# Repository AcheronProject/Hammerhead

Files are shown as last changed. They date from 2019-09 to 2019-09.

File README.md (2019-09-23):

# Acheron 40-SM-S-STM32-MXSM-TH-WI (Codename "Hammerhead")

Acheron Logo

See [this page](https://gondolindrim.github.io/AcheronDocs/hammerhead/intro.html) for the Hammerhead documentation.

## Introduction

The Hammerhead is named after the SharkPCB; in order to differentiate Hammerhead (which features a staggered layout) from the Shark (which features an ortho layout), I renamed the staggered version like so.

This PCB was born as a replacement PCB for an AMJ40 keyboard I have. I bought it from a user on r/mechmarket for a fairly cheap price, since the stock kit PCB was not working due to that previous owner using a Dremel tool and breaking a few traces on the PCB. After fixing the stock PCB it did work for three years, and I set myself to devise another PCB for it. As such, Hammerhead is fully compatible with the AMJ40 case.

## Supported layouts

Click [this link](http://www.keyboard-layout-editor.com/#/gists/89c3a984e836b351fcaf27332abd0f3e) for the KLE file for the Hammerhead.

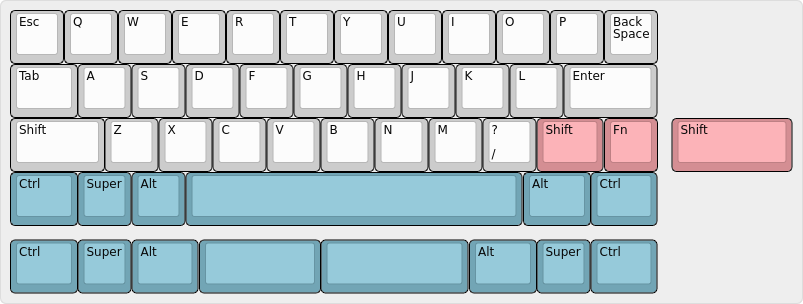
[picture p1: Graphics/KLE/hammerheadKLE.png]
Hammherhead layouts


## Renders

Click at the images to zoom in.

Renders generated by the [tracespace.io](https://tracespace.io/view/) site.

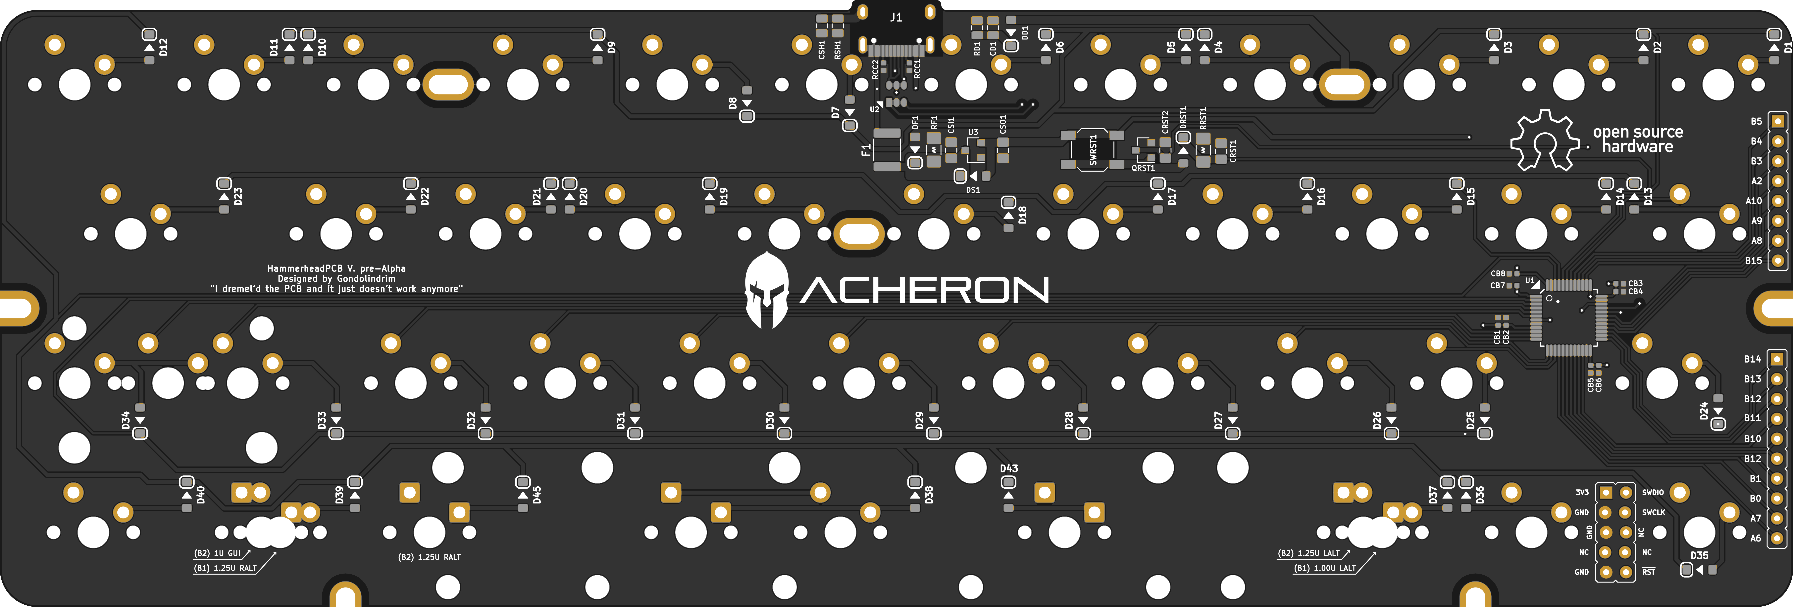
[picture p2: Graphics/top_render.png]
Hammerhead PCB Top Render


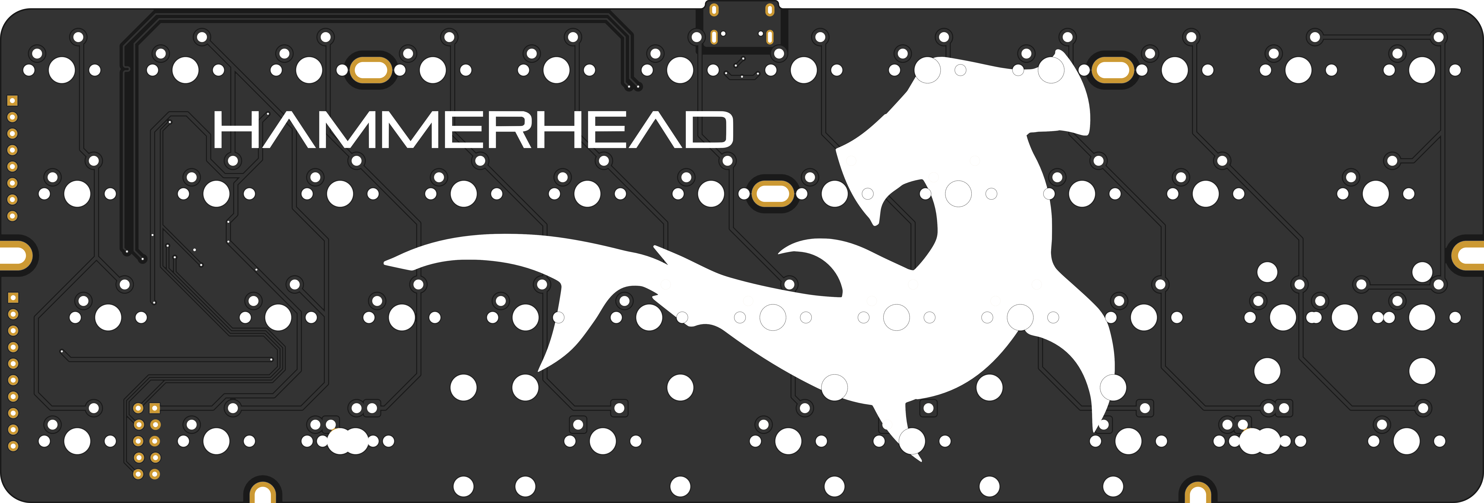
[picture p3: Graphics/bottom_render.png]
Hammerhead PCB Bottom Render


## Copyright notice

This project is released under the Acheron Open-Hardware Licence V1.1. For the license, please refer to the LICENCE.md file.

The Hammherhead icon used is a free-to-used icon that I downloaded from [this link](https://www.flaticon.com/free-icon/hammerhead-fish-shape_47439#term=hammerhead&page=1&position=2) at Freepik.com .

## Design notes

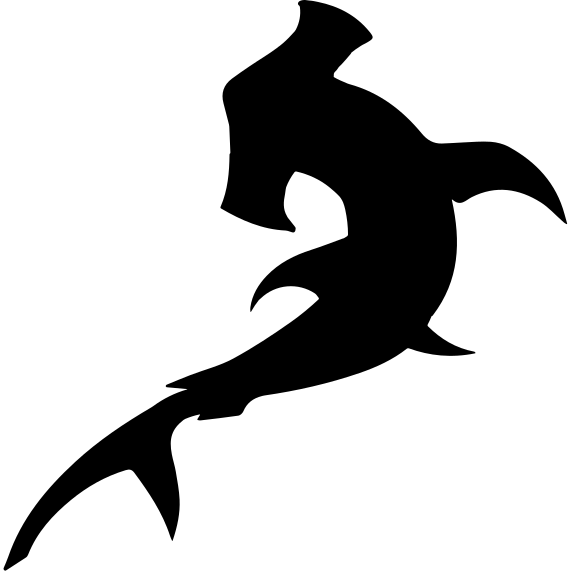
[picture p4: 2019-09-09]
Graphics/hammerhead-fish-shape.png

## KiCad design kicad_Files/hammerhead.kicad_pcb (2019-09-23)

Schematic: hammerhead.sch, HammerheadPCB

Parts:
CB1: 1uF; C_0402_1005Metric
CB2: 10n; C_0402_1005Metric
CB3, CB5, CB8: 100n; C_0402_1005Metric
CB4, CB6: 4.7uF; C_0402_1005Metric
CB7: 100nF; C_0402_1005Metric
CD1: 4.7nF; C_0805_2012Metric
CRST1: 10u; C_0805_2012Metric_Pad1.15x1.40mm_HandSolder
CRST2: 4.7n; C_0805_2012Metric_Pad1.15x1.40mm_HandSolder
CSH1: 4.7nF; C_0805_2012Metric
CSI1: 10u; C_0805_2012Metric_Pad1.15x1.40mm_HandSolder
CSO1: 1u; C_0805_2012Metric_Pad1.15x1.40mm_HandSolder
D1, D2, D3, D4, D5, D6, D7, D8, D9, D10, D11, D12, D13, D14, D15, D16, D17, D18, D19, D20, D21, D22, D23, D24, D25, D26, D27, D28, D29, D30, D31, D32, D33, D34, D35, D36, D37, D38, D39, D40, D43, D45: 1N4148; D_SOD-123
DD1: 1N4007; D_SOD-123
DF1: RB060M-60TR; D_SOD-123
DRST1: 1N4148; D_SOD-123
DS1: 1N4007; D_SOD-123
F1: Polyfuse; Fuse_1812_4532
H1, H6: Half Side Hole; halfSideHole
H2: Mounting Hole; MoutingHole_Oval_7mm_5.0x2.5mm
H3, H4, H5, H7: Oval Mounting Hole; MoutingHole_Oval_7mm_5.0x2.5mm
J1: TYPE-C-31-M12_13; TYPE-C-31-M-12
J2: Conn_ARM_JTAG_SWD_10
J3: Conn_01x08; PinHeader_1x8_P2.54mm_Vertical
J4: Conn_01x08; PinHeader_1x10_P2.54mm_Vertical
L1: HammerheadLogo; hammerhead_Logo
L2: OSHLogo; osh-logo
L3: Acheron Logo; acheronLong
QRST1: DTC123J; SOT-23
RCC1, RCC2: 5.1k; R_0402_1005Metric
RD1: 1M; R_0805_2012Metric
RF1: 10k; R_SMD_1026
RRST1: 100k; R_SMD_1026
RSH1: 1M; R_0805_2012Metric
SW1: ESC; MX100
SW2: Q; MX100
SW3: W; MX100
SW4: E; MX100
SW5: R; MX100
SW6: T; MX100
SW7: Y; MX100
SW8: U; MX100
SW9: I; MX100
SW10: O; MX100
SW11: P; MX100
SW12: BKSP; MX100
SW13: TAB_125; MX125
SW14: A; MX100
SW15: S; MX100
SW16: D; MX100
SW17: F; MX100
SW18: G; MX100
SW19: H; MX100
SW20: J; MX100
SW21: K; MX100
SW22: L; MX100
SW23: ENTER_175; MX175
SW24: LSHIFT_175; MX175
SW25: Z; MX100
SW26: X; MX100
SW27: C; MX100
SW28: V; MX100
SW29: B; MX100
SW30: N; MX100
SW31: M; MX100
SW32: /?; MX100
SW33: RSHIFT_125; MX125
SW34: FN_100; MX100
SW35: RSHIFT_225; MX225
SW36, SW46: SUPER_100; MX100
SW37: LALT_100; MX100
SW38: SPC_625; MX625R
SW39, SW45: RALT_125; MX125
SW40: LCTRL_125; MX125
SW41: RCTRL_125; MX125
SW42: LALT_125; MX125
SW43: SPC_225; MX225R
SW44: SPC_275; MX275R
SWRST1: SW_Push; smdPushBtn
U1: STM32F072-LQFP48; LQFP-48_7x7mm_P0.5mm
U2: USBLC6-2SC6; SOT-23-6
U3: MCP1700-3302E_SOT23; SOT-23

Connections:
3.3V: CB1.2, CB2.2, CB3.2, CB4.2, CB5.2, CB6.2, CB7.1, CB8.2, CSO1.2, DS1.2 (A), J2.1 (VTref), SWRST1.1, U1.1 (VBAT), U1.9 (VDDA), U1.24 (VDD), U1.36 (VDDIO2), U1.48 (VDD), U3.2 (VO)
5V: CSI1.2, DF1.1 (K), DS1.1 (K), F1.1, RF1.2, U3.3 (VI)
/SHIELD: CSH1.2, J1.S (SHIELD), RSH1.1
BOOT0: CRST1.2, DRST1.1 (K), RRST1.2, U1.44 (BOOT0)
CASE: DD1.2 (A), H5.1
Col1: SW1.1 (Col), SW13.1 (Col), SW24.1 (Col), SW40.1 (Col), U1.42 (I2C1_SCL/PB6)
Col2: SW2.1 (Col), SW14.1 (Col), SW25.1 (Col), SW36.1 (Col), U1.15 (PA5/ADC_IN5/DAC_OUT2)
Col3: SW3.1 (Col), SW15.1 (Col), SW26.1 (Col), SW37.1 (Col), SW42.1 (Col), U1.14 (PA4/TIM14_CH1/ADC_IN4)
Col4: SW4.1 (Col), SW16.1 (Col), SW27.1 (Col), SW44.1 (Col), U1.13 (PA3/TIM15_CH2/ADC_IN3)
Col5: SW5.1 (Col), SW17.1 (Col), SW28.1 (Col), U1.12 (PA2/ADC_IN2)
Col6: SW6.1 (Col), SW18.1 (Col), SW29.1 (Col), SW38.1 (Col), SW43.1 (Col), U1.11 (PA1/ADC_IN1)
Col7: SW7.1 (Col), SW19.1 (Col), SW30.1 (Col), U1.10 (PA0/ADC_IN0)
Col8: SW8.1 (Col), SW20.1 (Col), SW31.1 (Col), SW45.1 (Col), U1.6 (PF1/OSC_OUT)
Col9: SW9.1 (Col), SW21.1 (Col), SW32.1 (Col), SW39.1 (Col), SW46.1 (Col), U1.5 (PF0/OSC_IN)
Col10: SW10.1 (Col), SW22.1 (Col), SW33.1 (Col), SW41.1 (Col), U1.4 (PC15/OSC32_OUT)
Col11: SW11.1 (Col), SW12.1 (Col), SW23.1 (Col), SW34.1 (Col), SW35.1 (Col), U1.3 (PC14/OSC32_IN)
D+: U1.33 (USB_DP/PA12), U2.3 (IO2)
D-: U1.32 (USB_DM/TIM1_CH4/PA11), U2.1 (IO1)
DBus+: J1.A7 (D-), J1.B7 (D-), U2.4 (IO2)
DBus-: J1.A6 (D+), J1.B6 (D+), U2.6 (IO1)
Extra1: J3.1, U1.41 (SPI1_MOSI/I2S1_SD/TIM3_CH2/PB5)
Extra2: J3.2, U1.40 (SPI1_MISO/I2S1_MCK/TIM3_CH1/PB4)
Extra3: J3.3, U1.39 (SPI1_SCK/I2S1_CK/TIM2_CH2/PB3)
Extra4: J3.4, U1.38 (PA2)
Extra5: J3.5, U1.31 (TIM1_CH3/PA10)
Extra6: J3.6, U1.30 (TIM1_CH2/PA9)
Extra7: J3.7, U1.29 (TIM1_CH1/PA8)
Extra8: J3.8, U1.28 (SPI2_MOSI/I2S2_SD/PB15)
Extra9: J4.1, U1.27 (PB14/SPI2_MISO/I2S2_MCK/I2C2_SDA/TIM15_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)
Extra10: J4.2, U1.26 (SPI2_SCK/I2S2_CK/I2C2_SCL/PB13)
Extra11: J4.3, U1.25 (PB12)
Extra12: J4.4, U1.22 (PB11/TIM2_CH4/I2C2_SDA)
Extra13: J4.5, U1.21 (PB10/SPI2_SCK/I2C2_SCL/TIM2_CH3)
Extra14: J4.6, U1.20 (PB2)
Extra15: J4.7, U1.19 (PB1/TIM3_CH4/TIM14_CH1/ADC_IN9)
Extra16: J4.8, U1.18 (PB0/TIM3_CH3/ADC_IN8)
Extra17: J4.9, U1.17 (PA7/TIM3_CH2/TIM14_CH1/ADC_IN7)
Extra18: J4.10, U1.16 (PA6/ADC_IN6/TIM3_CH1/TIM16_CH1)
GND: CB1.1, CB2.1, CB3.1, CB4.1, CB5.1, CB6.1, CB7.2, CB8.1, CD1.1, CRST1.1, CRST2.2, CSH1.1, CSI1.1, CSO1.1, DF1.2 (A), J1.A1 (GND), J1.B1 (GND), J2.3 (GND), J2.5 (GND), J2.9 (GNDDetect), QRST1.2 (E), RCC1.1, RCC2.1, RD1.2, RF1.1, RRST1.1, RSH1.2, U1.8 (VSSA), U1.23 (VSS), U1.35 (VSS), U1.47 (VSS), U2.2 (GND), U3.1 (GND)
NRST: CRST2.1, J2.10 (~RESET~), QRST1.3 (C), U1.7 (NRST)
unnamed: CD1.2, DD1.1 (K), RD1.1
unnamed: D1.2 (A), SW1.2 (Row)
unnamed: D2.2 (A), SW2.2 (Row)
unnamed: D3.2 (A), SW3.2 (Row)
unnamed: D4.2 (A), SW4.2 (Row)
unnamed: D5.2 (A), SW5.2 (Row)
unnamed: D6.2 (A), SW6.2 (Row)
unnamed: D7.2 (A), SW7.2 (Row)
unnamed: D8.2 (A), SW8.2 (Row)
unnamed: D9.2 (A), SW9.2 (Row)
unnamed: D10.2 (A), SW10.2 (Row)
unnamed: D11.2 (A), SW11.2 (Row)
unnamed: D12.2 (A), SW12.2 (Row)
unnamed: D13.2 (A), SW13.2 (Row)
unnamed: D14.2 (A), SW14.2 (Row)
unnamed: D15.2 (A), SW15.2 (Row)
unnamed: D16.2 (A), SW16.2 (Row)
unnamed: D17.2 (A), SW17.2 (Row)
unnamed: D18.2 (A), SW18.2 (Row)
unnamed: D19.2 (A), SW19.2 (Row)
unnamed: D20.2 (A), SW20.2 (Row)
unnamed: D21.2 (A), SW21.2 (Row)
unnamed: D22.2 (A), SW22.2 (Row)
unnamed: D23.2 (A), SW23.2 (Row)
unnamed: D24.2 (A), SW24.2 (Row)
unnamed: D25.2 (A), SW25.2 (Row)
unnamed: D26.2 (A), SW26.2 (Row)
unnamed: D27.2 (A), SW27.2 (Row)
unnamed: D28.2 (A), SW28.2 (Row)
unnamed: D29.2 (A), SW29.2 (Row)
unnamed: D30.2 (A), SW30.2 (Row)
unnamed: D31.2 (A), SW31.2 (Row)
unnamed: D32.2 (A), SW32.2 (Row)
unnamed: D33.2 (A), SW33.2 (Row)
unnamed: D34.2 (A), SW34.2 (Row), SW35.2 (Row)
unnamed: D35.2 (A), SW40.2 (Row)
unnamed: D36.2 (A), SW36.2 (Row)
unnamed: D37.2 (A), SW37.2 (Row), SW42.2 (Row)
unnamed: D38.2 (A), SW38.2 (Row), SW43.2 (Row)
unnamed: D39.2 (A), SW39.2 (Row), SW46.2 (Row)
unnamed: D40.2 (A), SW41.2 (Row)
unnamed: D43.2 (A), SW44.2 (Row)
unnamed: D45.2 (A), SW45.2 (Row)
unnamed: DRST1.2 (A), QRST1.1 (B), SWRST1.2
unnamed: J1.A5 (CC1), RCC1.2
unnamed: J1.B5 (CC2), RCC2.2
Row1: D1.1 (K), D2.1 (K), D3.1 (K), D4.1 (K), D5.1 (K), D6.1 (K), D7.1 (K), D8.1 (K), D9.1 (K), D10.1 (K), D11.1 (K), U1.43 (2C1_SDA/PB7)
Row2: D13.1 (K), D14.1 (K), D15.1 (K), D16.1 (K), D17.1 (K), D18.1 (K), D19.1 (K), D20.1 (K), D21.1 (K), D22.1 (K), D23.1 (K), U1.45 (I2C1_SCL/TIM16_CH1/PB8)
Row3: D24.1 (K), D25.1 (K), D26.1 (K), D27.1 (K), D28.1 (K), D29.1 (K), D30.1 (K), D31.1 (K), D32.1 (K), D33.1 (K), D34.1 (K), U1.2 (PC13)
Row4: D12.1 (K), D35.1 (K), D36.1 (K), D37.1 (K), D38.1 (K), D39.1 (K), D40.1 (K), D43.1 (K), D45.1 (K), U1.46 (SPI2_NSS/I2S2_WS/I2C1_SDA/TIM17_CH1/PB9)
SWCLK: J2.4 (SWDCLK/TCK), U1.37 (SWCLK/PA14)
SWDIO: J2.2 (SWDIO/TMS), U1.34 (SWDIO/PA13)
VBUS: F1.2, J1.A4 (VBUS), J1.B4 (VBUS), U2.5 (VBUS)

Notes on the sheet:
Hard reset circuit
Power supply and protection circuit
Logos and flags
Serial programming
[1] STM32F072x8 / STM32F072xB datasheet
REFERENCES
https://www.st.com/resource/en/datasheet/stm32f072rb.pdf
[2] AN4080 Application note
https://www.st.com/content/ccc/resource/technical/document/application_note/c9/19/d7/b8/6b/0e/4c/d3/DM00051986.pdf/files/DM00051986.pdf/jcr:content/translations/en.D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
MCU
USB Connector
Shield
USD ESD
CBx are the bypass capacitors. Their value is specified in reference [2].
Case ESD

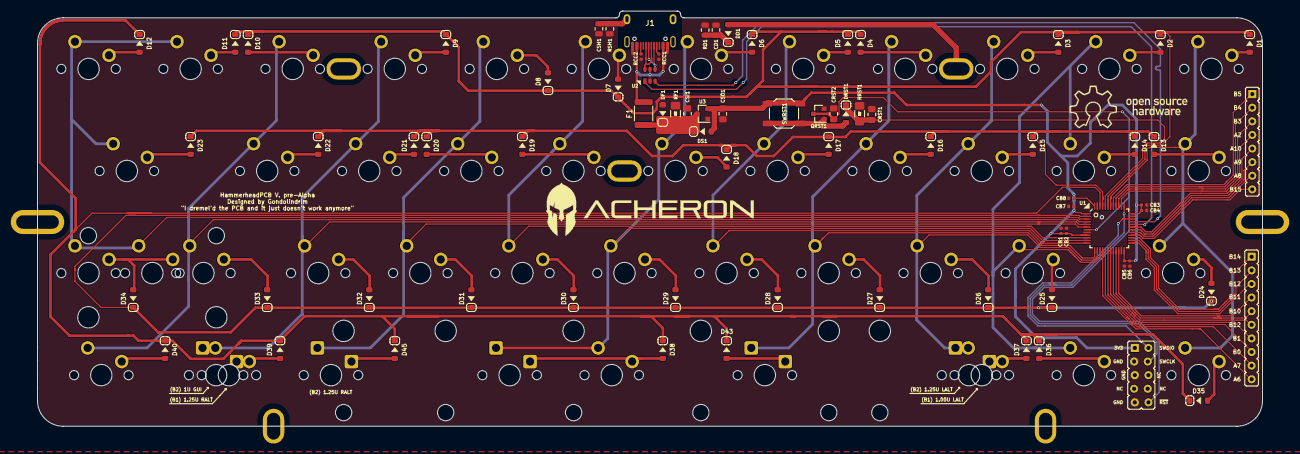
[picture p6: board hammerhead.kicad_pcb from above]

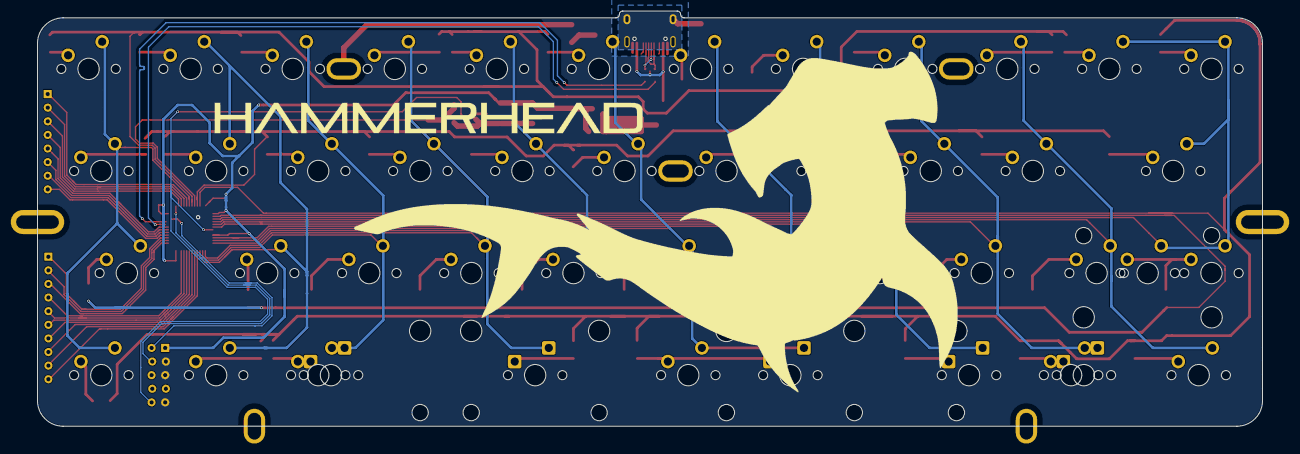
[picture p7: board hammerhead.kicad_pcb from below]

Board: 2 copper layers, 228.6 x 77.5 mm, 132 parts (8 on the bottom side), 93 nets.

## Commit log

2019-09-14 Finished routing
    [hammerhead-B_Cu.gbr, hammerhead-B_Mask.gbr, hammerhead-B_Paste.gbr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]
2019-09-23 Added extra pins breakouts
    [hammerhead-B_Cu.gbr, hammerhead-B_Mask.gbr, hammerhead-B_Paste.gbr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]
2019-09-23 Updated renders and README
    [hammerhead.kicad_pcb]
2019-09-23 Updt: preparations for pre-Alpha release
    [hammerhead.kicad_pcb]
